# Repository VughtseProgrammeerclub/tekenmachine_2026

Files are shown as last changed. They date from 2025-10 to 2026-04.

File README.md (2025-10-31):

# tekenmachine\_2026

## Weer een VPC-project

Bij de clubbijeenkomst zijn er drie ideeën overgebleven voor een nieuw programmeerproject waarbij we een tekenmachine gaan maken:

1. Pantograaf (twee armen)
2. Polargraph (koordplotter)
3. Tekenkarretje ???

### Pantograaf

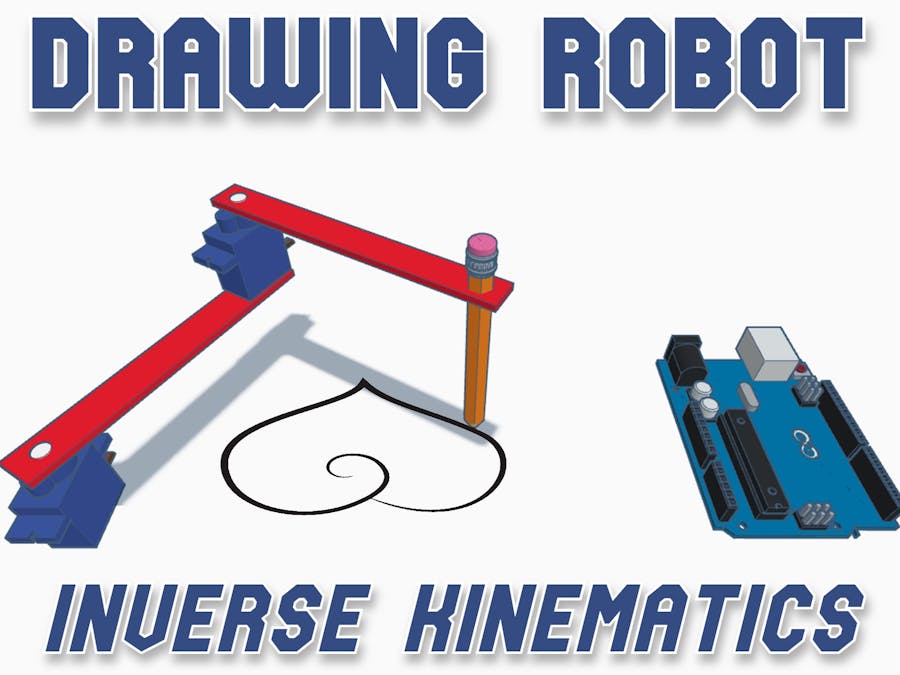
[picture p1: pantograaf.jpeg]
Pantograaf


Voorbeeld: https://youtu.be/GRJwoxl9V6U?si=yc7fQQzsjecvV63H

* Kan worden gedaan met Arduino, Raspberry Pi Pico of micro:bit
* Kritische onderdelen zijn de drie servo's. Je kan aan de slag met de bijzonder goedkope blauwe SG90-servo's (€ 2 per stuk), maar met een servo van ongeveer € 5-10 met metalen tandwielen is het resultaat zeker beter. Voor deze eenvoudige servo's zijn geen aparte driverbordjes nodig. Wel moet je rekening houden met een aparte 5V-voeding.
* Exclusief microcontroller moet dit voor **€ 20-30** te bouwen zijn.

### Polargraaf

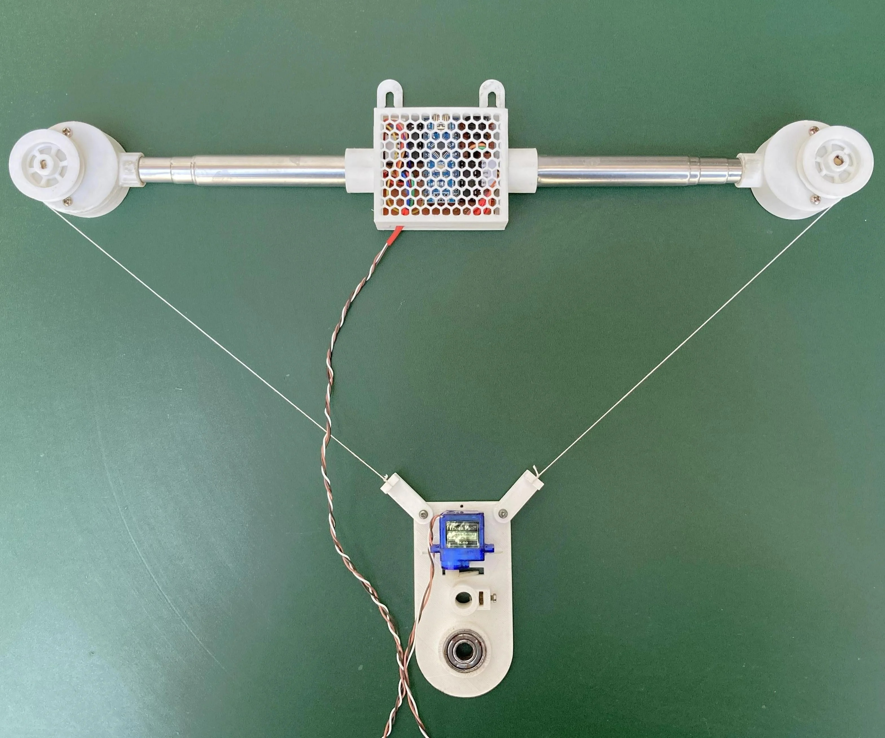
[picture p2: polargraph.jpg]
Polargraaf


Voorbeeld: https://www.hackster.io/mertarduino/drawing-robot-board-polargraph-plotter-240e14

* Kan worden gedaan met Arduino, Raspberry Pi Pico of micro:bit
* Hiervoor hebben twee stappenmotoren en één servo nodig. De goedkoopste stappenmotoren inclusief driver kosten € 2-5 per stuk (https://www.tinytronics.nl/nl/mechanica-en-actuatoren/motoren/stappenmotoren/stappen-motor-met-uln2003-motoraansturing). De servo hoeft hier niet van de beste kwaliteit te zijn (€ 2 per stuk). Voor een beter resultaat is een wat betere stappenmotor wel aan te bevelen. Deze kosten € 10-15 per stuk(https://www.tinytronics.nl/nl/mechanica-en-actuatoren/motoren/stappenmotoren/stappenmotor-0.14n.m-1a-nema14-jst-ph-connector), hierbij komt dan nog twee drivers van een paar Euro per stuk (https://nl.aliexpress.com/item/1005009465430336.html).
* Verder ook nog wat mechaninische onderdelen zoals zoals getande pulley's en tandriemen.
* Exclusief microcontroller dam moet dit, afhankelijk van de gekozen stappenmotoren) te bouwen zijn voor **€ 20-50**.

### Tekenkarretje ???

Hier heb ik nog goed over nagedacht. Twee jaar geleden heb ik bij Huis73 een project gedan met een Arduino-robotkarretje. Hier heb ik nog de meeste spullen voor, maar het was achteraf gezien best wel een complex project em om enigszinds naukeurig te kunnen tekenen heb je goede motoren en wielen nodig. Ik denk dat dit te complex, te duur (minimaal € 50) en te veel voorbereidingstijd gaat kosten. Als er echter mensen zijn die de uitdaging aan willen gaan dankan dat natuurlijk altijd en er zijn ook voldoende mensen om te helpen/adviseren.

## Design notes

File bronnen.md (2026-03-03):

# Belangrijkste bron

Op deze GitHub is een vergelijkbaar project beschreven, alleen met een Raspberry Pi in plaats van met een Raspberry Pi Pico. 
* [https://github.com/evildmp/BrachioGraph](https://github.com/evildmp/BrachioGraph)

# Verschillen
| Kenmerk | Raspberry Pi | Raspberry Pi Pico |
| --- | --- | --- |
| Type apparaat | Mini-computer | Microcontroller |
| Besturingssysteem | Ja (Linux) | Nee |
| Python | Volledige CPython | MicroPython |
| Geheugen | GB’s | kB’s |
| Libraries | Bijna alles | Beperkt |
| Geschikt voor | Software, servers, AI | Elektronica, realtime besturing |

# Programeeromgeving Thonny of Visual Studio Code (VS Code)
* https://thonny.org/ (voor beginners)
* https://code.visualstudio.com/ (wat serieuzer)

# Presentatie 3-3-2026
* https://docs.google.com/presentation/d/1sXPqOY21omOXEBFrHBQ5wQfQpdithJy6pYmlmKh20rY/edit?usp=sharing

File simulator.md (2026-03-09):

# Simulator tekenarmen

In de documentatie van het voorbeeldproject https://www.brachiograph.art/ staat een simulato waarmee je kan zien wat het tekenbereik is bij verschillende start- en draaihoeken van de tekenarmen. Deze simulatie is gebouwd in (hoe kan het anders) Python.

<p align="center">
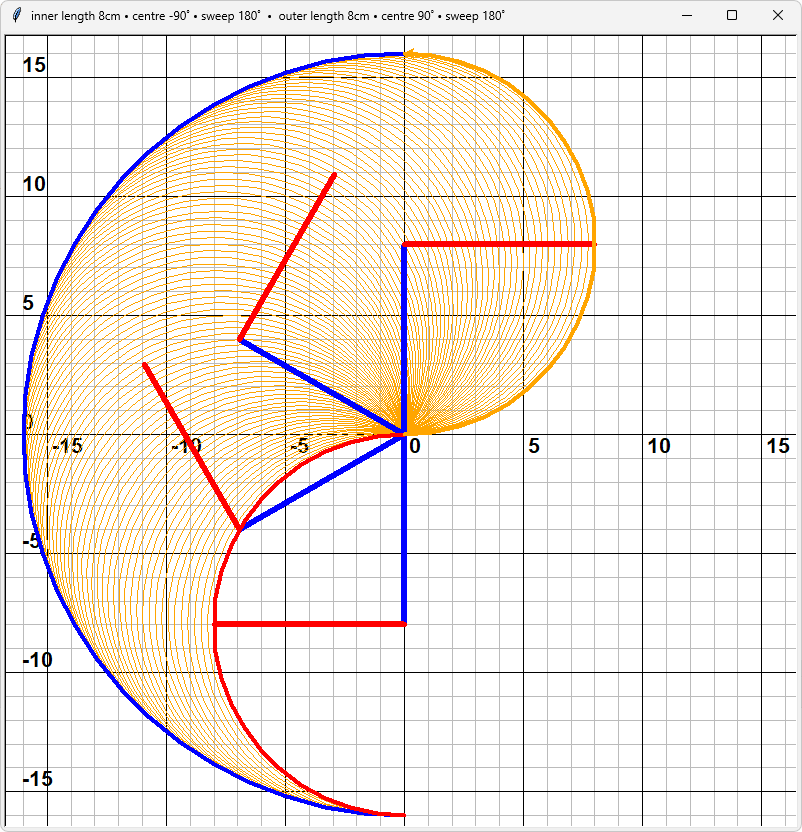
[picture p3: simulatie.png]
  
</p>
De blauwe lijn is de bovenarm
De rode lijn is de onderarm

## bgt.py
De simulatie zit volgens de documentatie in bgt.py. Dit bestand zit inderdaad in de GitHub van Brachiograph (dus **niet** de GitHub van de Vughtse Programmeer Club) die te vinden is op https://github.com/evildmp/BrachioGraph/tree/main. 
Ik heb eerst geprobeerd om het bestand te downloaden en te starten in Thonny, maar dat gaf allerlei foutmeldingen. Rudy gaf me deze tip om de simulatie toch aan de gang te krijgen:
<p align="center">
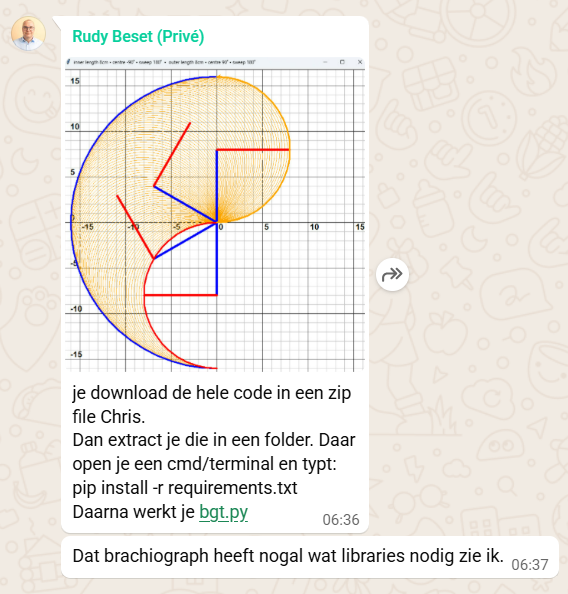
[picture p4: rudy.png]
  
</p>

Dit is echter de Linux-oplossing en ik werk op Windows. Dit zijn de stappen om het in Windows voor elkaar te krijgen. **Ik ga er vanuit dat je Python-programmeeromgeving (bijvoorbeeld Thonny) al hebt geïnstalleerd.**
### Stap 1: De Github downloaden
Ik heb voor het gemak de hele Github https://github.com/evildmp/BrachioGraph/tree/main gedownload. Dat gaat zo:
<p align="center">
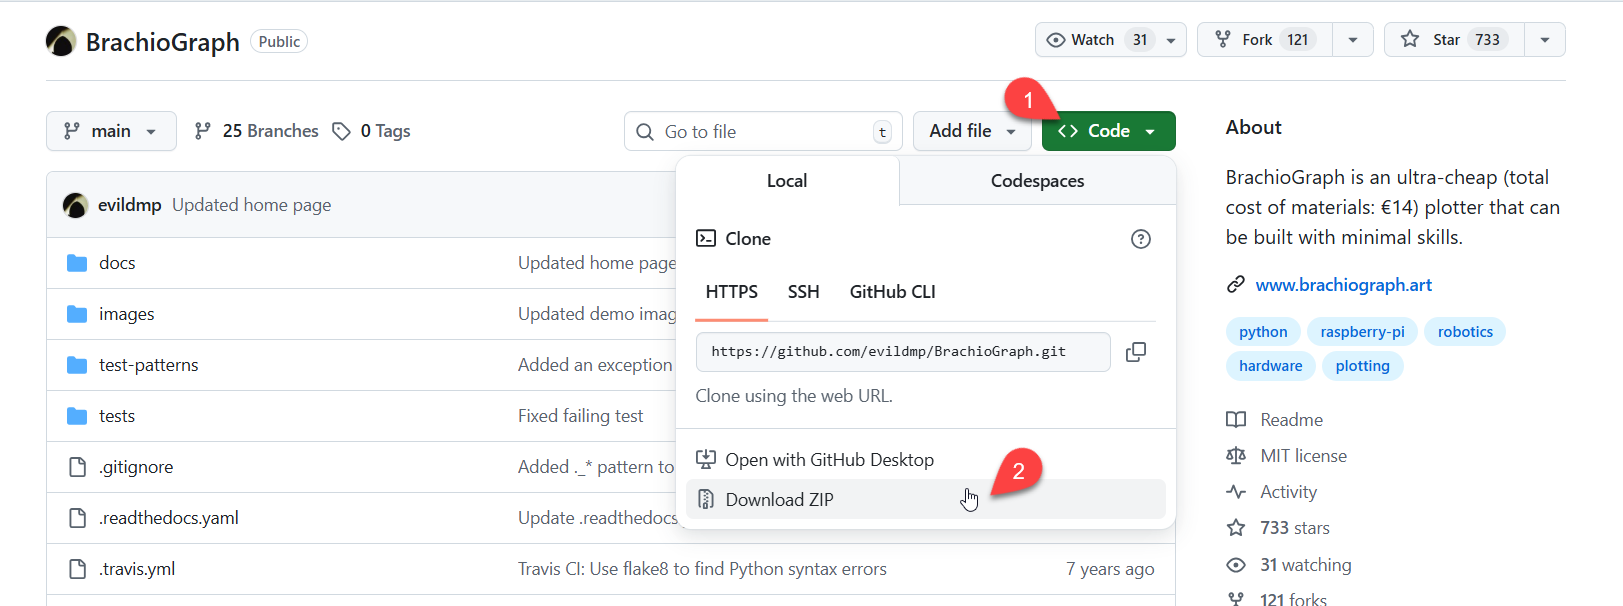
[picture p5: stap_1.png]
  
</p>

1. Zorg dat je in *Main* bent en ga naar [<> Code]
2. Kies hier *Download ZIP*

### Stap 2: ZIP-bestand uitpakken (ongeveer 43 Mb)
Pak het gedwonloade ZIP-bestand uit.

### Stap 3: bgt.py starten vanuit Thonny
1. Start Thonny
2. Open bgt.py
3. Start het programma
4. Pas de hoeken aan

Dat ziet er zo uit:
<p align="center">
<a href="https://youtu.be/xvEm5joO8kY">

</a>
</p>

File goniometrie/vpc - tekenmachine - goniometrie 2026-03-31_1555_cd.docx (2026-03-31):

α=arctan⁡(y/x)

L= √(x^2 +y^2)

l= L/2

β=arccos(l/8)

γ=180°- (2×β)

α

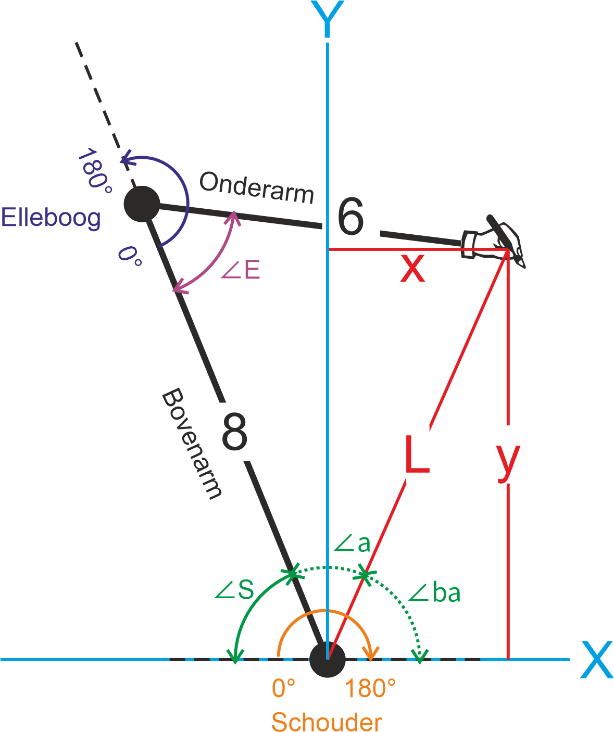
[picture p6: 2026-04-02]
goniometrie.png

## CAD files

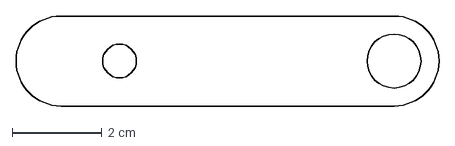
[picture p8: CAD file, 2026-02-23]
VPC Tekenproject - Onderarm.dxf
9.40 x 2.00 cm

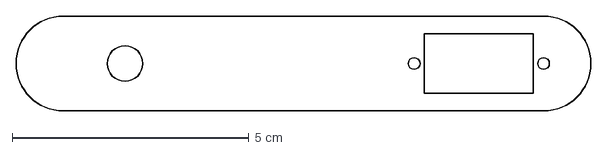
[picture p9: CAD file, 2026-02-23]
VPC Tekenproject - Bovenarm.dxf
12.1 x 2.00 cm

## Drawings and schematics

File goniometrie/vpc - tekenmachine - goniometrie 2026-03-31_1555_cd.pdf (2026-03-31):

X

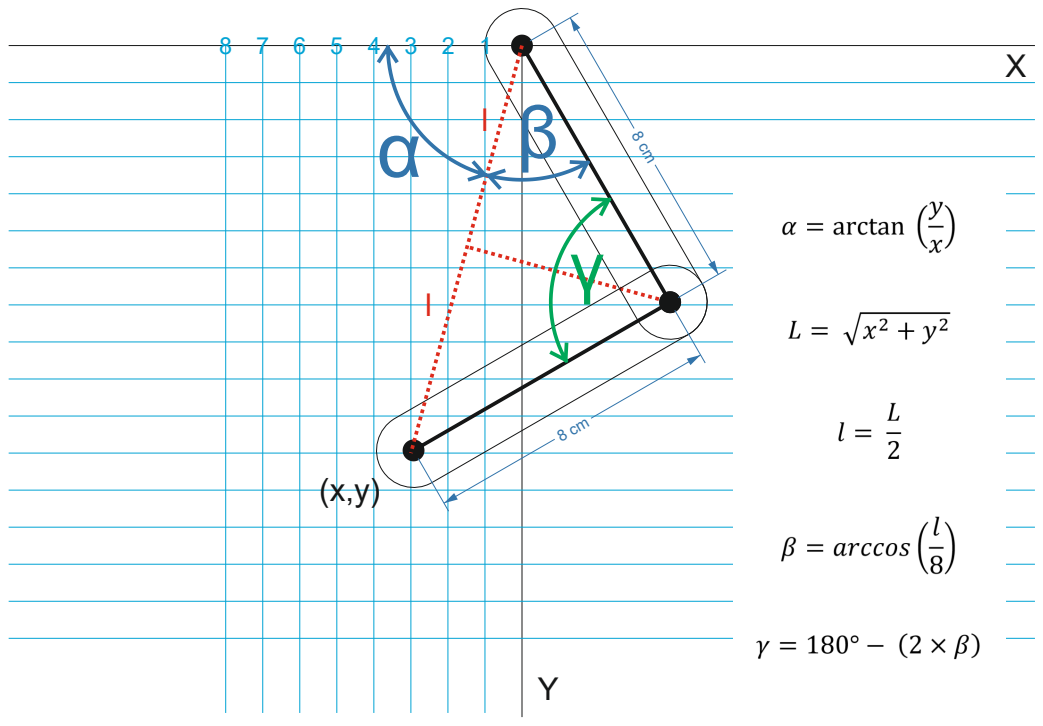
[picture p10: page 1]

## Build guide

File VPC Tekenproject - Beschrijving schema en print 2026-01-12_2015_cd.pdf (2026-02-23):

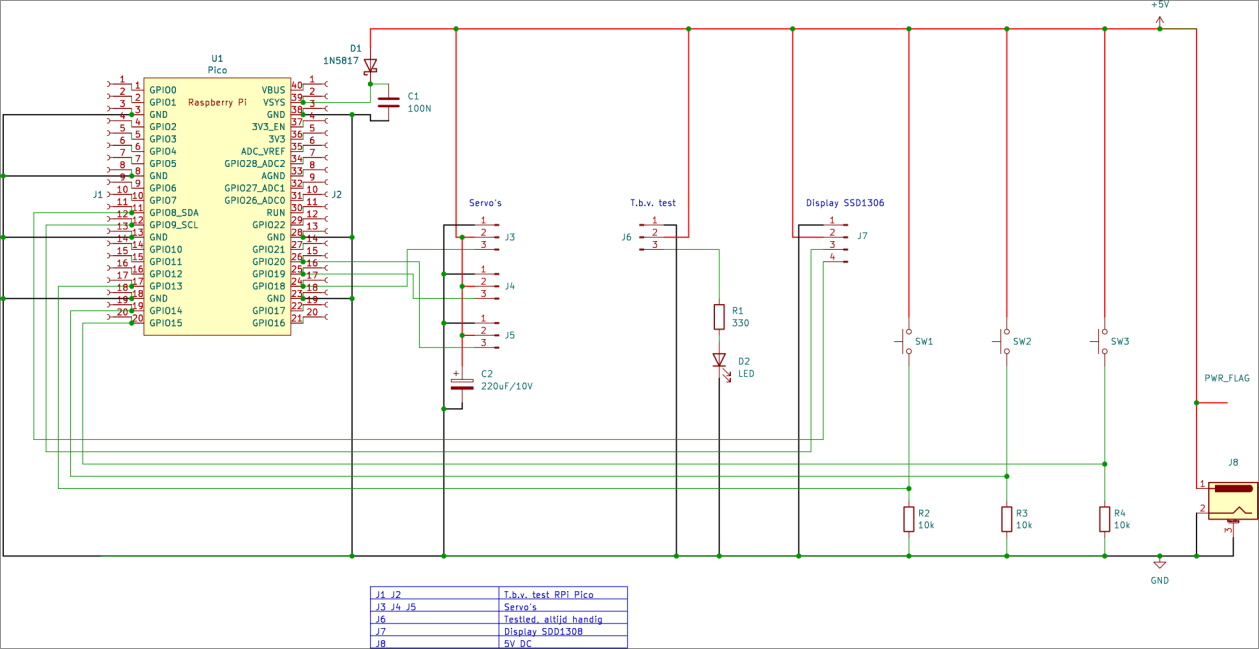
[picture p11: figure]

1

## Doel van het schema

Dit schema hoort bij een project van de Vughtse Programmeer Club (VPC). Het project is bedoeld om op een praktische manier kennis te maken met programmeren en elektronica.
De print stuurt een eenvoudige tekenrobot aan. Het ontwerp is gemaakt om te leren, testen en experimenteren.

## Wat doet de schakeling?

Op de print wordt een Raspberry Pi Pico aangesloten. Deze microcontroller bestuurt alle onderdelen van de tekenrobot.
Overzicht GPIO-pinnen
GPIO | Onderdeel | Functie
GPIO 18 Servo | Servo schouder
GPIO 19 Servo | Servo elleboog
GPIO 20 Servo | Servo pols / pen
GPIO 8 Display (optioneel) SDA – I²C data
GPIO 9 Display (optioneel) SCL – I²C klok
GPIO 13 Schakelaar | Vrij inzetbaar voor experimenten
GPIO 14 Schakelaar | Vrij inzetbaar voor experimenten
GPIO 15 Schakelaar | Vrij inzetbaar voor experimenten

De functie van de schakelaars wordt in de software bepaald.

## Voeding

- 5 V – voeding voor servo’s en display

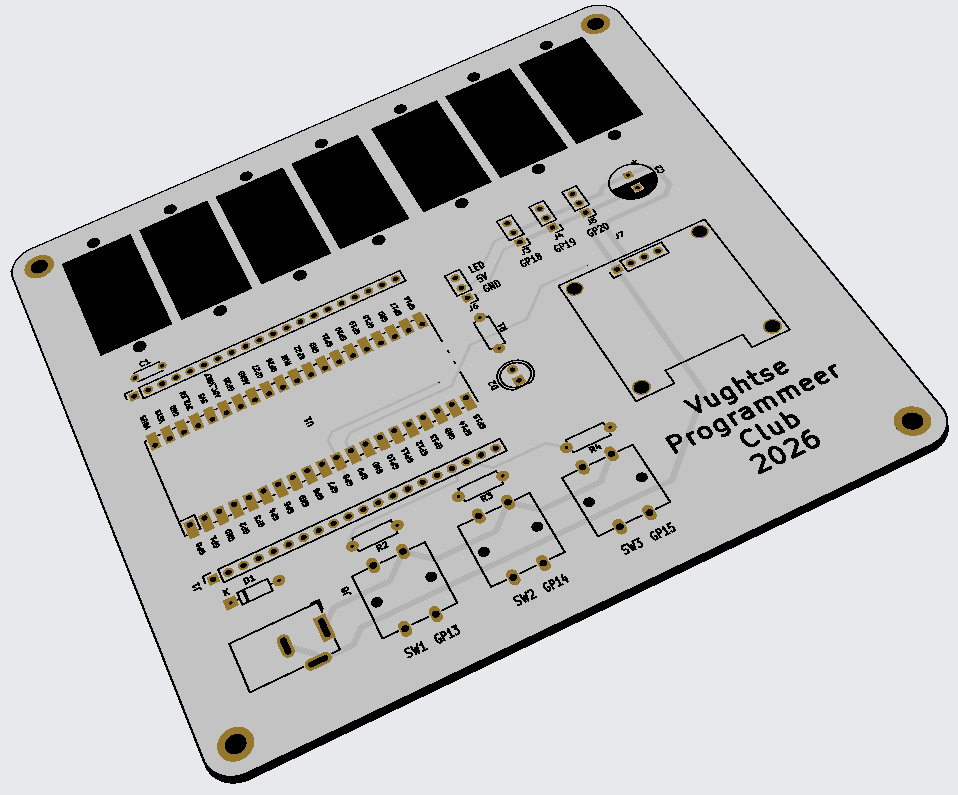
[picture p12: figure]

2

- GND – gemeenschappelijke massa

## Print

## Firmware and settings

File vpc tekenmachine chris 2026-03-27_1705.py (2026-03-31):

# =========================================================
# PROGRAMMA VPC TEKENROBOT
# =========================================================
# Dit programma bestuurt een robotarm met:
# - schouder
# - elleboog
# - penmechanisme
#
# Op het OLED-scherm verschijnt tekst.
# Met knoppen kan elke servo bewogen worden.


# =========================================================
# BIBLIOTHEKEN
# =========================================================
from machine import Pin, PWM, I2C
# Pin → knoppen en digitale signalen
# PWM → servo aansturen
# I2C → communicatie met OLED-scherm

import time
# time → pauzes in het programma

import framebuf
# framebuf → beeld in geheugen opbouwen voor OLED


# =========================================================
# OLED INSTELLING
# =========================================================
ADDR = 0x3C
i2c = I2C(0, sda=Pin(8), scl=Pin(9), freq=20000)


class SSD1306_I2C:

    def __init__(self, width, height, i2c, addr=0x3C):
        self.width = width
        self.height = height
        self.i2c = i2c
        self.addr = addr
        self.pages = self.height // 8

        self.buffer = bytearray(self.pages * self.width)

        self.fb = framebuf.FrameBuffer(
            self.buffer,
            self.width,
            self.height,
            framebuf.MONO_VLSB
        )

        self.init_display()

    def writeto_retry(self, data, tries=8, delay_ms=5):
        for _ in range(tries):
            try:
                self.i2c.writeto(self.addr, data)
                return
            except OSError:
                time.sleep_ms(delay_ms)

        # Laatste poging
        self.i2c.writeto(self.addr, data)

    def cmd(self, c):
        self.writeto_retry(bytes([0x00, c]))
        time.sleep_ms(2)

    def init_display(self):
        # OLED 180° draaien (display zit ondersteboven)
        for c in (
            0xAE, 0xD5, 0x80, 0xA8, 0x3F, 0xD3, 0x00, 0x40,
            0x8D, 0x14, 0x20, 0x00,
            0xA0,  # horizontaal omdraaien
            0xC0,  # verticaal omdraaien
            0xDA, 0x12,
            0x81, 0xCF, 0xD9, 0xF1,
            0xDB, 0x40, 0xA4, 0xA6, 0xAF
        ):
            self.cmd(c)

        self.fill(0)
        self.show()

    def fill(self, col):
        self.fb.fill(col)

    def text(self, s, x, y):
        self.fb.text(s, x, y)

    def show(self):
        self.cmd(0x21)
        self.cmd(0)
        self.cmd(self.width - 1)
        self.cmd(0x22)
        self.cmd(0)
        self.cmd(self.pages - 1)

        # De buffer in kleine stukken versturen
        # Dit is stabieler dan alles in één keer sturen
        chunk = 32
        for i in range(0, len(self.buffer), chunk):
            self.writeto_retry(b"\x40" + self.buffer[i:i + chunk])
            time.sleep_ms(1)


oled = SSD1306_I2C(128, 64, i2c, addr=ADDR)


def oled_message(l1="", l2="", l3=""):
    oled.fill(0)
    oled.text(l1, 0, 0)
    oled.text(l2, 0, 16)
    oled.text(l3, 0, 32)
    oled.show()


# =========================================================
# KNOPPEN
# =========================================================
button_schouder = Pin(13, Pin.IN, Pin.PULL_DOWN)
button_elleboog = Pin(14, Pin.IN, Pin.PULL_DOWN)
button_pen = Pin(15, Pin.IN, Pin.PULL_DOWN)


# =========================================================
# SERVO'S
# =========================================================
servo_schouder = PWM(Pin(18))
servo_schouder.freq(50)

servo_elleboog = PWM(Pin(19))
servo_elleboog.freq(50)

servo_pen = PWM(Pin(20))
servo_pen.freq(50)


# =========================================================
# SERVO BEREIK
# =========================================================
# Deze waarden bepalen welk PWM-bereik hoort bij
# ongeveer 0 graden en 180 graden.
MIN_DUTY = 1638
MAX_DUTY = 8192


def angle_to_duty(angle):
    return int(MIN_DUTY + (angle / 180) * (MAX_DUTY - MIN_DUTY))


def set_servo_angle(servo, angle):
    servo.duty_u16(angle_to_duty(angle))




# =========================================================
# OPSTARTTEST
# =========================================================
oled_message("VPC Tekenrobot", "Opstarten", "")
servoSchouderStart = 150
servoElleboogStart = 120
set_servo_angle(servo_schouder, servoSchouderStart)
set_servo_angle(servo_elleboog, servoElleboogStart)
set_servo_angle(servo_pen, 90)

time.sleep(1)
oled_message("Test", "Schouder", "")
set_servo_angle(servo_schouder, servoSchouderStart - 5)
time.sleep(0.5)
set_servo_angle(servo_schouder, servoSchouderStart)
time.sleep(0.5)
set_servo_angle(servo_schouder, servoSchouderStart + 5)
time.sleep(0.5)
set_servo_angle(servo_schouder, servoSchouderStart)
time.sleep(0.5)

oled_message("Test", "Elleboog", "")
set_servo_angle(servo_elleboog, servoElleboogStart - 5)
time.sleep(0.5)
set_servo_angle(servo_elleboog, servoElleboogStart)
time.sleep(0.5)
set_servo_angle(servo_elleboog, servoElleboogStart + 5)
time.sleep(0.5)
set_servo_angle(servo_elleboog, servoElleboogStart)
time.sleep(0.5)

oled_message("Test", "Pen", "")
set_servo_angle(servo_pen, 90 - 15)
time.sleep(0.5)
set_servo_angle(servo_pen, 90)
time.sleep(0.5)
set_servo_angle(servo_pen, 90 + 15)
time.sleep(0.5)
set_servo_angle(servo_pen, 90)
time.sleep(0.5)

oled_message("VPC Tekenrobot", f"Schouder: {servoSchouderStart}", f"Elleboog: {servoElleboogStart}")


# =========================================================
# HOOFDLUS
# =========================================================
while True:

    if button_schouder.value():

        oled_message("Servo", "Schouder", "")

        set_servo_angle(servo_schouder, 90 + 15)
        time.sleep(0.5)
        
        set_servo_angle(servo_schouder, 90)
        time.sleep(0.5)

        set_servo_angle(servo_schouder, 90 - 15)
        time.sleep(0.5)

        set_servo_angle(servo_schouder, 90)
        time.sleep(0.5)

        oled_message("VPC Tekenrobot", "Gereed", "Druk knop")

        while button_schouder.value():
            time.sleep(0.01)

    if button_elleboog.value():

        oled_message("Servo", "Elleboog", "")

        set_servo_angle(servo_elleboog, 90 + 15)
        time.sleep(0.5)

        set_servo_angle(servo_elleboog, 90)
        time.sleep(0.5)
        
        set_servo_angle(servo_elleboog, 90 - 15)
        time.sleep(0.5)

        set_servo_angle(servo_elleboog, 90)
        time.sleep(0.5)

        oled_message("VPC Tekenrobot", "Gereed", "Druk knop")

        while button_elleboog.value():
            time.sleep(0.01)

    if button_pen.value():

        oled_message("Servo", "Pen", "")

        set_servo_angle(servo_pen, 90 + 45)
        time.sleep(0.5)

        set_servo_angle(servo_pen, 90)
        time.sleep(0.5)


        oled_message("VPC Tekenrobot", "Gereed", "Druk knop")

        while button_pen.value():
            time.sleep(0.01)

    time.sleep(0.01)

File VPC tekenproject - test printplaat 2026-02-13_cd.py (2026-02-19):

from machine import Pin, PWM, I2C
import time
import framebuf

# ================= OLED SETUP =================
# SSD1306 via I2C0 op GP8 (SDA) en GP9 (SCL)
# Lage I2C-frequentie omdat jouw display anders timeout-fouten gaf.
ADDR = 0x3C
i2c = I2C(0, sda=Pin(8), scl=Pin(9), freq=20000)


# ===== AANGEPASTE SSD1306 DRIVER =====
# Dit is een "slow/robust" variant.
# Belangrijk: bevat retries bij I2C-communicatie om OSError(110) te voorkomen.
class SSD1306_I2C_Slow:
    def __init__(self, width, height, i2c, addr=0x3C):
        self.width = width
        self.height = height
        self.i2c = i2c
        self.addr = addr
        self.pages = self.height // 8

        # Framebuffer bevat volledige beeldinhoud in RAM
        self.buffer = bytearray(self.pages * self.width)
        self.fb = framebuf.FrameBuffer(
            self.buffer,
            self.width,
            self.height,
            framebuf.MONO_VLSB
        )

        self.init_display()

    # Essentieel: herhaal I2C write bij tijdelijke fouten
    def _writeto_retry(self, data, tries=8, delay_ms=5):
        for _ in range(tries):
            try:
                self.i2c.writeto(self.addr, data)
                return
            except OSError:
                time.sleep_ms(delay_ms)
        self.i2c.writeto(self.addr, data)

    # Stuurt een commando (control byte 0x00)
    def cmd(self, c):
        self._writeto_retry(bytes([0x00, c]))
        time.sleep_ms(2)

    # SSD1306 initialisatie-sequentie
    # Dit zet resolutie, scanrichting, charge pump enz.
    def init_display(self):
        for c in (
            0xAE, 0xD5, 0x80, 0xA8, 0x3F, 0xD3, 0x00, 0x40,
            0x8D, 0x14, 0x20, 0x00, 0xA1, 0xC8, 0xDA, 0x12,
            0x81, 0xCF, 0xD9, 0xF1, 0xDB, 0x40, 0xA4, 0xA6, 0xAF
        ):
            self.cmd(c)
        self.fill(0)
        self.show()

    def fill(self, col):
        self.fb.fill(col)

    def text(self, s, x, y):
        self.fb.text(s, x, y)

    def pixel(self, x, y, col=1):
        self.fb.pixel(x, y, col)

    # Belangrijk:
    # Eerst kolom + pagina-adres instellen,
    # daarna framebuffer in kleine blokken versturen.
    def show(self):
        self.cmd(0x21); self.cmd(0); self.cmd(self.width - 1)
        self.cmd(0x22); self.cmd(0); self.cmd(self.pages - 1)

        CHUNK = 32  # kleine blokken om I2C stabiel te houden
        for i in range(0, len(self.buffer), CHUNK):
            self._writeto_retry(b"\x40" + self.buffer[i:i+CHUNK])
            time.sleep_ms(1)


oled = SSD1306_I2C_Slow(128, 64, i2c, addr=ADDR)


# ================= OLED HELPER =================
# dot_state wordt gebruikt voor het knipperpuntje rechtsboven
dot_state = False

def oled_message(line1="", line2="", line3=""):
    oled.fill(0)

    if line1: oled.text(line1, 0, 0)
    if line2: oled.text(line2, 0, 16)
    if line3: oled.text(line3, 0, 32)

    # Speciaal: knipperend statuspuntje rechtsboven
    x0, y0 = 124, 0
    col = 1 if dot_state else 0
    for dx in range(3):
        for dy in range(3):
            oled.pixel(x0 + dx, y0 + dy, col)

    oled.show()


# ================= SERVO SETUP =================
pairs = [
    (13, 18),
    (14, 19),
    (15, 20),
]

led_onboard = Pin(25, Pin.OUT)
led_ext = Pin(16, Pin.OUT)

# Belangrijk:
# 50 Hz is standaard voor analoge servo's.
SERVO_FREQ = 50

# Deze waarden bepalen het PWM bereik (0° en 180°)
# Afhankelijk van servo kunnen deze iets verschillen.
MIN_DUTY = 1638
MAX_DUTY = 8192

def angle_to_duty(angle):
    return int(MIN_DUTY + (angle / 180) * (MAX_DUTY - MIN_DUTY))

def set_servo_angle(pwm, angle):
    pwm.duty_u16(angle_to_duty(angle))


# Servo's en knoppen initialiseren
buttons = {}
servos = {}

for btn_gpio, srv_gpio in pairs:
    buttons[btn_gpio] = Pin(btn_gpio, Pin.IN, Pin.PULL_DOWN)

    pwm = PWM(Pin(srv_gpio))
    pwm.freq(SERVO_FREQ)
    servos[btn_gpio] = pwm

    # Startpositie = 0 graden
    set_servo_angle(pwm, 0)


# ================= SOEPELE SERVO-BEWEGING =================
# Deze functie is blokkerend.
# Tijdens uitvoeren wordt geen andere knop verwerkt.
STEP_DELAY = 0.02   # bepaalt snelheid
STEP_SIZE  = 2      # bepaalt vloeiendheid

def move_once_slow(pwm):

    # Vooruit
    for angle in range(0, 181, STEP_SIZE):
        set_servo_angle(pwm, angle)
        time.sleep(STEP_DELAY)

    # Terug
    for angle in range(180, -1, -STEP_SIZE):
        set_servo_angle(pwm, angle)
        time.sleep(STEP_DELAY)


# ================= KNIPPER-TIMING =================
# Wordt gebruikt voor:
# - LED's
# - OLED statuspuntje
last_toggle = time.ticks_ms()
LED_INTERVAL = 300


# ================= MAIN LOOP =================
oled_message("VPC Tekenrobot", "Gereed", "Druk knop")

while True:
    now = time.ticks_ms()

    # LED + OLED puntje laten knipperen
    if time.ticks_diff(now, last_toggle) > LED_INTERVAL:
        led_onboard.toggle()
        led_ext.toggle()

        dot_state = not dot_state
        last_toggle = now

        oled_message("VPC Tekenrobot", "Gereed", "Druk knop")

    # Knoppen controleren
    # Let op: blokkerend door move_once_slow()
    for btn_gpio in (13, 14, 15):
        if buttons[btn_gpio].value() == 1:

            oled_message("Servo actief", f"GPIO {btn_gpio}", "")

            move_once_slow(servos[btn_gpio])

            oled_message("VPC Tekenrobot", "Gereed", "")

            # wachten tot knop losgelaten is
            while buttons[btn_gpio].value() == 1:
                time.sleep(0.01)

    time.sleep(0.005)

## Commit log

2026-03-15 Create VPC tekenproject - test printplaat 2026-03-15_1505_cd.py
    Aanzienlijk eenvoudigere versie
2026-03-15 Rename VPC tekenproject - test printplaat 2026-02-13_2025.py to VPC tekenproject - test printplaat 2026-02-13_cd.py
2026-03-17 Fotos toegevoegd van de assemblage
